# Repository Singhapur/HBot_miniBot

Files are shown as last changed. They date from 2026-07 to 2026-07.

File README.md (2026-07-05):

# 🤖 HBot_miniBot

Final Degree Project (Bachelor’s Thesis) repository to build a **miniBot** based on a distributed architecture using Arduino, Raspberry Pi, and ESP32.

This project documents the complete process, from physical construction (CAD design and 3D printing) to programming and integration of the different systems using ROS 2 and AI computer vision.

---

# 📌 Description

**HBot_miniBot** is an advanced educational and practical project that combines:

- **Low-Level Hardware Control:** Arduino for strict real-time motor PWM control and ESP32 for high-frequency (200Hz) telemetry (IMU & LiDAR).
- **High-Level Processing:** Raspberry Pi 5 acting as the brain, running ROS 2 (Ubuntu Server) for odometry, waypoint navigation, and Visual Servoing.
- **Artificial Intelligence:** Real-time human tracking using the YOLO11-pose model (Ultralytics) running directly on the edge.
- **Wireless Communication:** DDS network topology allowing seamless monitoring and teleoperation from a remote laptop via RViz2.

---

# 🏗 Construction

This section describes the complete miniBot building process. The chassis is 100% custom-designed focusing on modularity and maintenance.

- **Chassis design:** Modeled in CAD and optimized for FDM 3D printing.
- **Prototyping:** Dimensional validation performed using wood cardboard before final manufacturing.
- **Fabrication:** Final structural parts printed in PETG using an Original Prusa MK3S for superior thermal and mechanical resistance.
- **Hardware integration:** Tiered design (drive level, logic level, and sensor level). 

Images, schematics, and assembly recommendations will be included here.
imagen

---

# 📦 Bill of Materials (BOM)

## 🔩 Electronics

- Raspberry Pi 5 (Main brain)
- Arduino Uno / Nano (Motor & Actuator controller)
- ESP32 (Sensor bridge)
- Motor driver (L298N, L293D Shield, or similar)
- 1D LiDAR / Distance Sensor
- IMU (Inertial Measurement Unit)
- USB Camera
- 7.4V LiPo Battery (for motors)
- External power bank (5V 3A) for Raspberry Pi
- Breadboard and Dupont wires

## ⚙ Mechanics

- Custom 3D-Printed chassis (PETG)
- 4x TT DC motors with wheels and encoders
- 1x Servomotor (for camera/sensor panning)
- M3 Screws and nuts
- Brass standoffs / Spacers

---

# 💻 Software

The software architecture is divided into microcontroller firmware and a ROS 2 workspace. 

## 1. Microcontroller Firmware (C/C++)
Located in the `/arduino_esp_code` folder:
- **Arduino Code (arduino_code.ino):** Handles hardware interrupts for wheel encoders and translates binary serial commands into PWM signals for the DC motors. Includes an emergency stop trigger.
- **ESP32 Code (MPU_Luna.ino):** Samples the IMU and distance sensors at high speeds and streams the data to the Pi using a custom binary protocol with Checksum validation.

## 2. ROS 2 Workspace (Python)
Located in the `/robot_tfg_pkg/robot_tfg_pkg` folder. This is the core logic of the robot:

- `arduino_bridge.py` & `esp32_bridge.py`: Serial interfaces translating raw binary data to standard ROS 2 messages (`Twist`, `Imu`).
- `odometry_node.py`: Fuses encoder data with IMU gyroscope readings to estimate the robot's real-time position in the world.
- `camera_reader_yolo.py`: Captures video, runs YOLO11n-pose inference, and calculates visual servoing errors to center the target using the servo and chassis movement.
- `high_level_controller.py`: The main Finite State Machine (FSM). Handles pure alignment, waypoint navigation, deadband compensation, and emergency braking.
- `waypoint_sender.py`: A node that safely dispatches navigation coordinates once the DDS network is fully discovered.

---

# 🔧 Assembly

General assembly steps:

1. Validate dimensions with cardboard prototypes.
2. 3D Print the chassis layers in PETG.
3. Mount the TT motors and encoders onto the bottom chassis.
4. Attach the motor driver and power distribution system.
5. Install Arduino, Raspberry Pi, and ESP32 on their respective deck levels.
6. Mount the articulated neck for the camera and the top turret for the LiDAR.
7. Verify electrical connections (⚠ **Important:** Check polarities before powering the system).

## Testing Model

In this model we will see how the 3D model would actually look like, and also be able to start programming the functionalities.

- Base without ESP32 and Arduino case
  
  

- Completed base

  

- Testing model completed

  
  
## 3D Printed Model


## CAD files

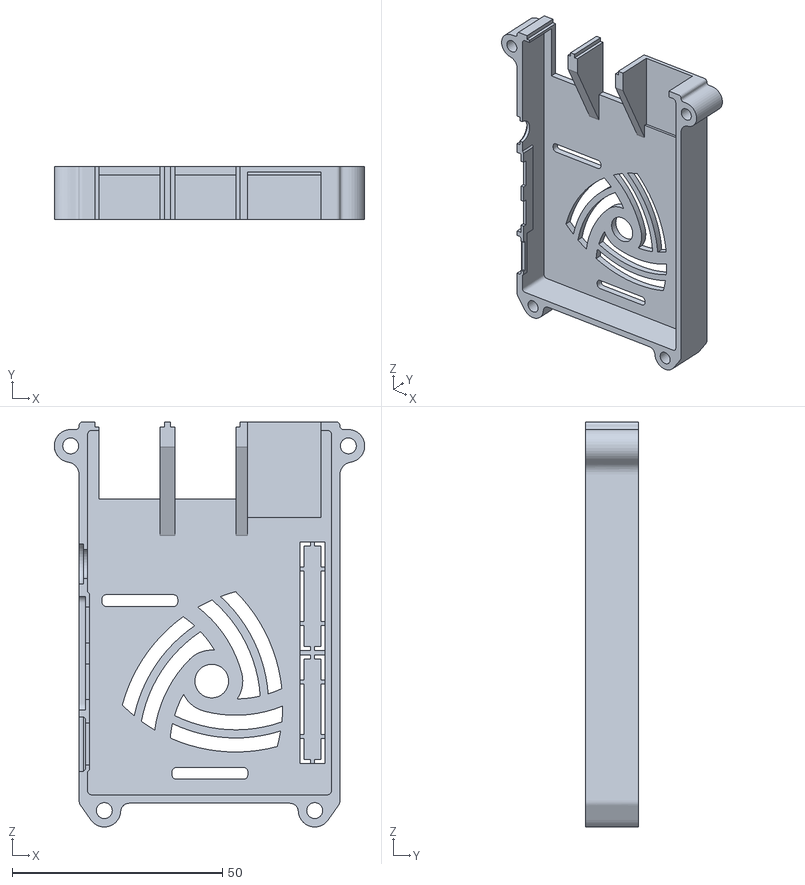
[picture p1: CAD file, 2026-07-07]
stl_models/Rpi_4_Case_Top_official_rPI_HDMI_cable.stl
73.8 x 12.5 x 96.2

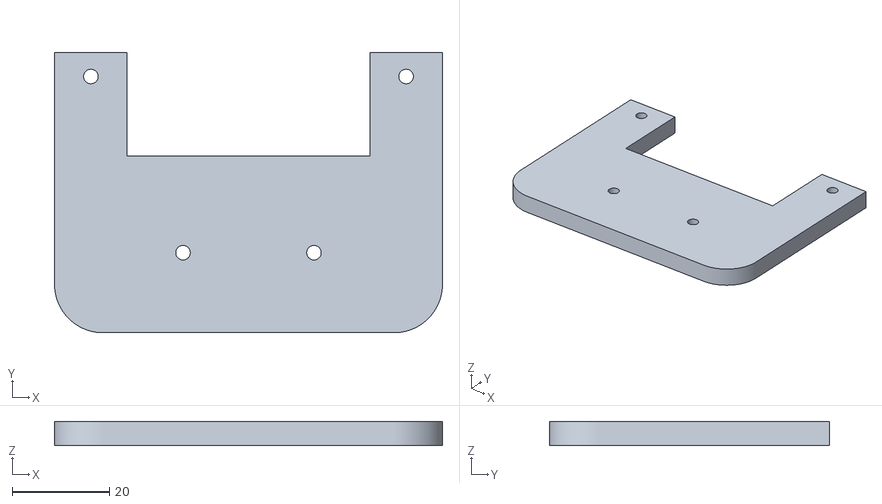
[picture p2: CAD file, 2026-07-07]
stl_models/PlataformaServo.stl
80.0 x 57.8 x 5.00

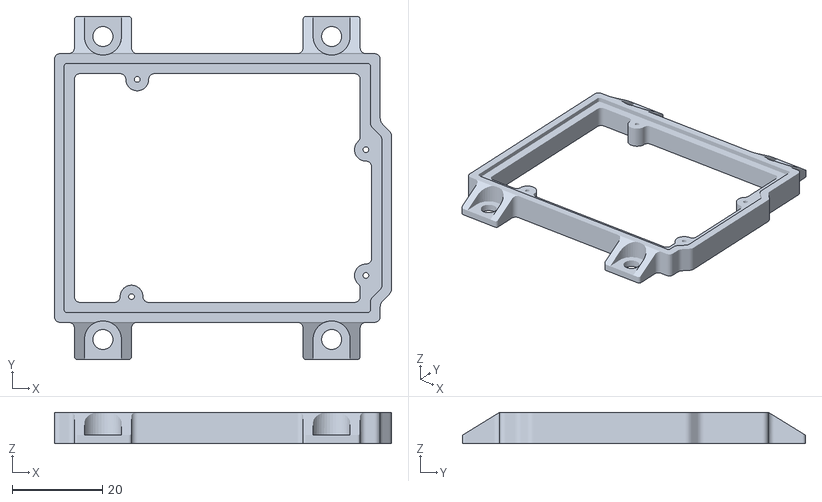
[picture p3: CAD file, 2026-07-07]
stl_models/UNO_R2_MOUNT.stl
74.9 x 76.2 x 6.99

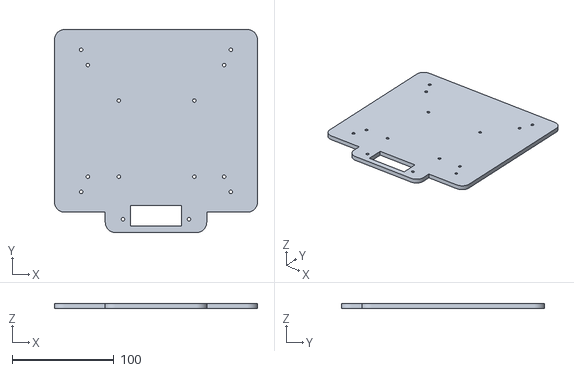
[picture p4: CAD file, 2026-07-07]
stl_models/Planta 2.stl
200.0 x 200.0 x 5.00

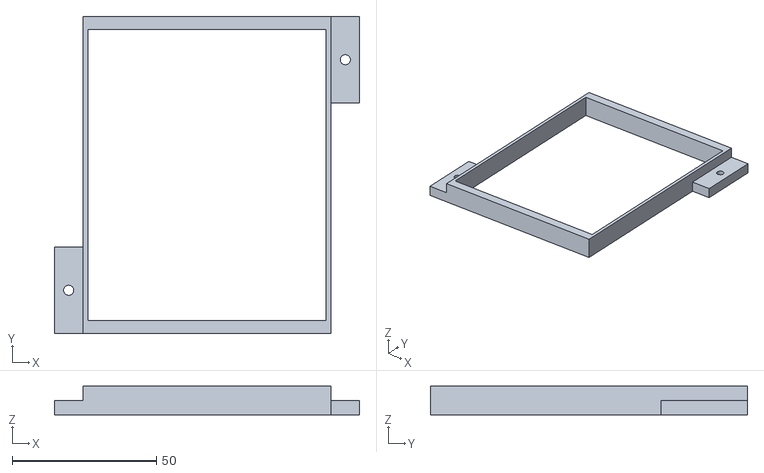
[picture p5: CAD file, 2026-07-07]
stl_models/protoboard case.stl
106.0 x 110.0 x 10.0

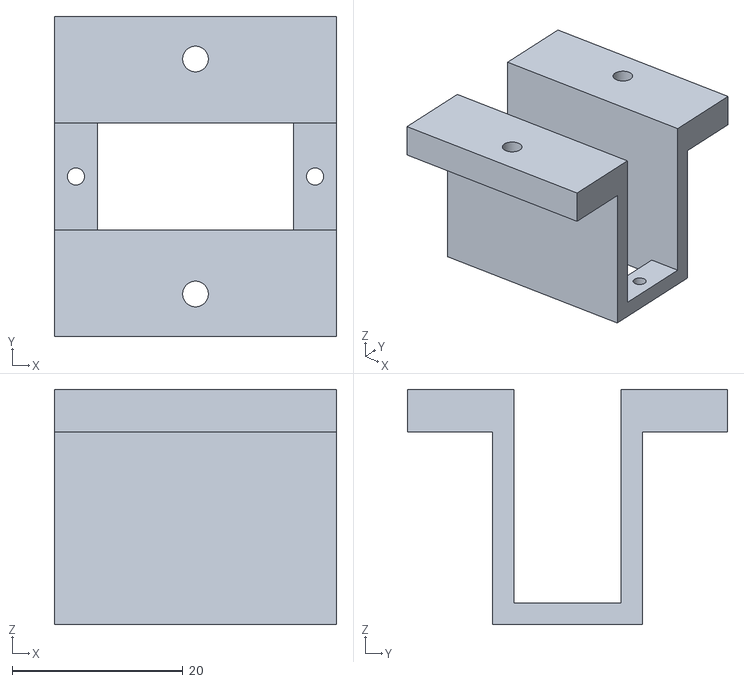
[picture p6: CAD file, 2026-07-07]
stl_models/soporte servo.stl
33.0 x 37.5 x 27.5

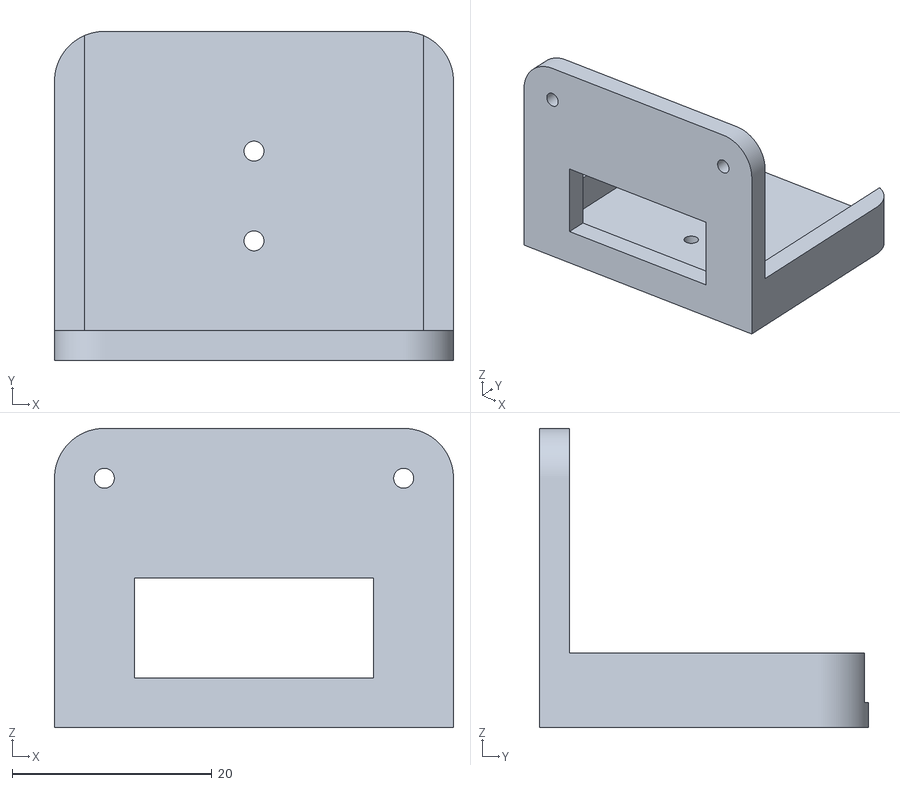
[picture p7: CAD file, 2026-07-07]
stl_models/Soporte Laser.stl
40.0 x 33.0 x 30.0

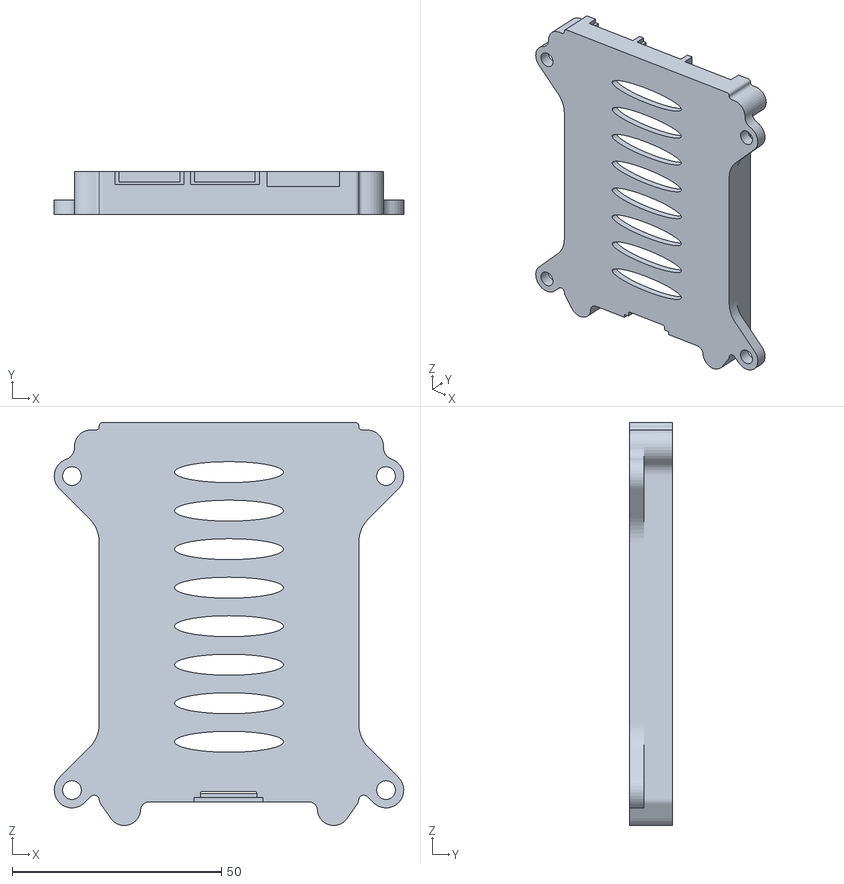
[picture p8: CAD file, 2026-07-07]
stl_models/Rpi_4_Case_Bottom_official_rPI_HDMI_cable.stl
83.5 x 10.3 x 96.2

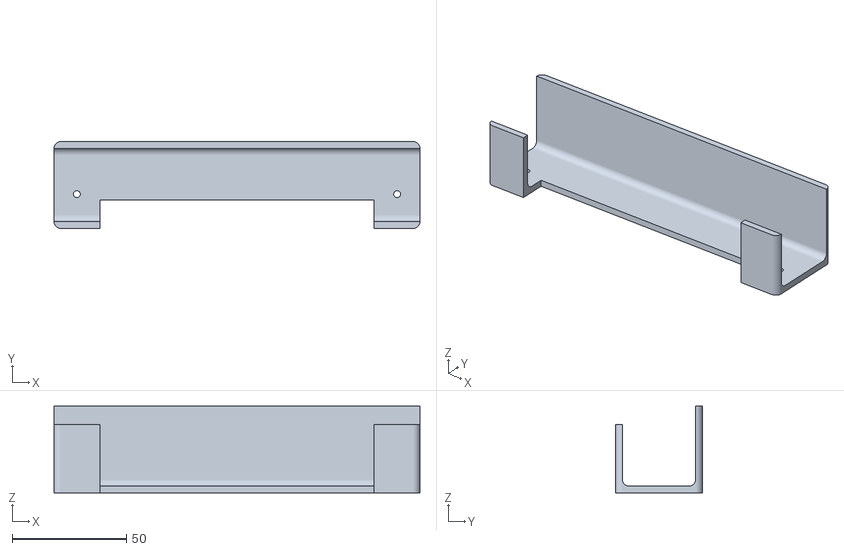
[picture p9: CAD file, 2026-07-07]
stl_models/Back Batery Suport.stl
160.0 x 38.0 x 38.0

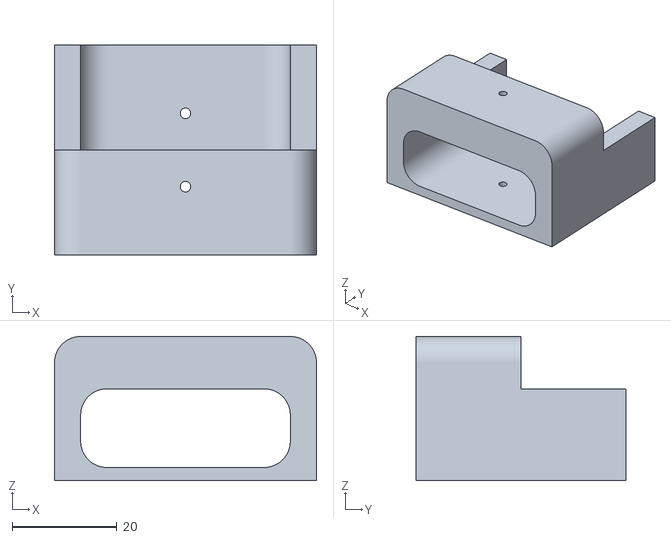
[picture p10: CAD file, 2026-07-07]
stl_models/Suport Camera.stl
50.0 x 40.0 x 27.5

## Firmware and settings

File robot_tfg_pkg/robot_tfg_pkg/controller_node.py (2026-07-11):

import rclpy
from rclpy.node import Node
from nav_msgs.msg import Odometry
from sensor_msgs.msg import Range
from geometry_msgs.msg import Twist
from std_msgs.msg import Int16MultiArray


class ControllerNode(Node):
    def __init__(self):
        super().__init__('controller_node')
        
        self.use_imu = True
        
        # Subscriptions
        self.sub_cmd_vel = self.create_subscription(Twist, '/cmd_vel', self.cmd_vel_callback, 10)
        self.sub_lidar = self.create_subscription(Range, '/sensor_distancia', self.distance_callback, 10)
        self.sub_odom = self.create_subscription(Odometry, '/odom', self.odom_callback, 10)
        
        # Publisher
        self.pub_pwm = self.create_publisher(Int16MultiArray, '/pwm_setpoints', 10)
        
        # Physical parameters
        self.wheelbase = 0.145
        self.max_speed_ms = 0.5

        # Smooth acceleration
        self.target_v = 0.0
        self.target_w = 0.0
        self.current_v = 0.0
        self.current_w = 0.0
        # Smooth acceleration variables 
        self.max_accel_v = 0.8 # m/s
        self.max_accel_w = 2.0 # rads/s

        self.max_decel_v = 5.0 # m/s 
        self.max_decel_w = 6.0 # rads/s
        self.dt = 0.1 # timer runs at 0.1 seconds
        
        # Sensor variables
        self.current_distance = 100.0 # meters
        self.min_distance = 0.20 # m  
        
        # State variables
        self.base_pwm_left = 0
        self.base_pwm_right = 0
        self.dir_left = 2 # 2=Release, 1=Forward, 0=Backward
        self.dir_right = 2
        self.straight_line_mode = False
        self.last_cmd_time = self.get_clock().now()
        self.last_pwm_left = 0
        self.last_pwm_right = 0
        
        
        # Memory for the Integral term
        self.error_fwd = 0.0
        self.error_bwd = 0.0
        
        # Timer to send PWM commands constantly
        self.timer = self.create_timer(0.1, self.publish_pwm)
        
        # PI Controller parameters
        self.kp = 4.5
        self.ki = 1.0

        # Deadband compensation
        self.MIN_PWM_STRAIGHT = 110
        self.MIN_PWM_TURN = 140
        
        self.get_logger().info('Trajectory PI Controller Started')
        
    def distance_callback(self, msg):
        self.current_distance = msg.range

    def cmd_vel_callback(self, msg):
        self.last_cmd_time = self.get_clock().now()
        v = msg.linear.x
        w = msg.angular.z
        self.target_v = msg.linear.x
        self.target_w = msg.angular.z

        if self.current_distance <= self.min_distance and self.target_v > 0:
            self.target_v = 0.0
            self.target_w = 0.0
            self.current_v = 0.0
            self.current_w = 0.0

    def odom_callback(self, msg):
        # We could use odometry data for additional control or state estimation if needed
        real_w = msg.twist.twist.angular.z

        # Apply PI if going in a straight line
        if self.straight_line_mode:
            
            error = -real_w * 10.0 
            
            integral_term = 0.0
            
            # Save error for Anti-Windup
            if self.dir_left == 1 and self.dir_right == 1:
                self.error_fwd += error
                self.error_fwd = max(-50.0, min(50.0, self.error_fwd))
                integral_term = self.error_fwd
                
            elif self.dir_left == 0 and self.dir_right == 0:
                self.error_bwd += error
                self.error_bwd = max(-50.0, min(50.0, self.error_bwd))
                integral_term = self.error_bwd

            # Correction Calculation: Proportional + Integral
            correction = int((error * self.kp) + (integral_term * self.ki))
            
            # Apply correction to the base PWM
            if self.last_pwm_left != 0 and self.last_pwm_right != 0:
                self.base_pwm_left = self.last_pwm_left - correction
                self.base_pwm_right = self.last_pwm_right + correction
            else:
                self.base_pwm_left -= correction
                self.base_pwm_right += correction
            
            self.base_pwm_left = max(95, min(255, self.base_pwm_left))
            self.last_pwm_left = self.base_pwm_left       
            self.base_pwm_right = max(95, min(255, self.base_pwm_right))
            self.last_pwm_right = self.base_pwm_right


    def assign_vel(self):
        # Smooth acceleration logic
        # Calculate the difference between what we want and what we have
        dv = self.target_v - self.current_v
        dw = self.target_w - self.current_w
        
        # We brake if the absolute target is smaller than the current one, or if we suddenly change direction
        is_braking_v = abs(self.target_v) < abs(self.current_v) or (self.target_v * self.current_v < 0)
        is_braking_w = abs(self.target_w) < abs(self.current_w) or (self.target_w * self.current_w < 0)
        
        # Assign the corresponding step limit
        step_limit_v = (self.max_decel_v if is_braking_v else self.max_accel_v) * self.dt
        step_limit_w = (self.max_decel_w if is_braking_w else self.max_accel_w) * self.dt
        
        # Apply linear ramp
        if abs(dv) > step_limit_v:
            self.current_v += step_limit_v if dv > 0 else -step_limit_v
        else:
            self.current_v = self.target_v
            
        # Apply angular ramp
        if abs(dw) > step_limit_w:
            self.current_w += step_limit_w if dw > 0 else -step_limit_w
        else:
            self.current_w = self.target_w

        # 3. Set speed
        v = self.current_v
        w = self.current_w

        # Straight line
        if abs(v) > 0.01 and abs(w) < 0.01:
            self.straight_line_mode = True
        else:
            self.straight_line_mode = False

        turn_factor = 1.0

        v_left = v - (w * turn_factor * self.wheelbase / 2.0)
        v_right = v + (w * turn_factor * self.wheelbase / 2.0)

        pwm_l = int(abs(v_left) * (255.0 / self.max_speed_ms))
        pwm_r = int(abs(v_right) * (255.0 / self.max_speed_ms))

        # Deadband compensation
        
        if self.straight_line_mode:      
            if 0 < pwm_l < self.MIN_PWM_STRAIGHT: pwm_l = self.MIN_PWM_STRAIGHT
            if 0 < pwm_r < self.MIN_PWM_STRAIGHT: pwm_r = self.MIN_PWM_STRAIGHT
        else:
            if 0 < pwm_l < self.MIN_PWM_TURN: pwm_l = self.MIN_PWM_TURN
            if 0 < pwm_r < self.MIN_PWM_TURN: pwm_r = self.MIN_PWM_TURN

        # Save the BASE from the kinematic calculation
        self.base_pwm_left = min(255, pwm_l)
        self.base_pwm_right = min(255, pwm_r)

        # Directions
        if v_left > 0.01: self.dir_left = 1
        elif v_left < -0.01: self.dir_left = 0
        else: self.dir_left = 2

        if v_right > 0.01: self.dir_right = 1
        elif v_right < -0.01: self.dir_right = 0
        else: self.dir_right = 2

    def publish_pwm(self):
        time_since_last_cmd = (self.get_clock().now() - self.last_cmd_time).nanoseconds / 1e9       
        # Watchdog: Stop robot if no command received in 0.2s
        if time_since_last_cmd > 0.2:
            self.base_pwm_left = 0
            self.base_pwm_right = 0
            self.dir_left = 2  # Release
            self.dir_right = 2 # Release
            self.straight_line_mode = False
            self.error_fwd = 0.0
            self.error_bwd = 0.0
            # New target for smooth stop
            self.target_v = 0.0
            self.target_w = 0.0
        
        self.assign_vel() 
            
        # Convert absolute values to signed values (positive/negative)
        val_left = self.base_pwm_left if self.dir_left == 1 else -self.base_pwm_left
        if self.dir_left == 2: val_left = 0
        
        val_right = self.base_pwm_right if self.dir_right == 1 else -self.base_pwm_right
        if self.dir_right == 2: val_right = 0
        
        msg_pwm = Int16MultiArray()
        msg_pwm.data = [val_left, val_right]
        self.pub_pwm.publish(msg_pwm)

def main(args=None):
    rclpy.init(args=args)
    node = ControllerNode()
    rclpy.spin(node)
    node.destroy_node()
    rclpy.shutdown()

if __name__ == '__main__':
    main()

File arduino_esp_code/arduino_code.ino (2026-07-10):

#include "AFMotor_R4.h"
#include <Servo.h>
#include <EnableInterrupt.h>

// --- BINARY COMMUNICATION PROTOCOL ---
#define START_BYTE 0xAA
#define END_BYTE   0x55
#define ID_ENCODERS 0x02
#define ID_CMD_MOTOR_SERVO 0x10

// --- DC MOTOR CONFIGURATION ---
AF_DCMotor M1(1); // Front left
AF_DCMotor M2(2); // Front right
AF_DCMotor M3(3); // Rear right
AF_DCMotor M4(4); // Rear left

// --- TWO SERVO CONFIGURATION ---
Servo cameraServo;
Servo lidarServo;

// --- ROBOT STATES ---
int left_pwm = 0;
int left_dir = RELEASE;
int right_pwm = 0;
int right_dir = RELEASE;
int camera_angle = 90;
int lidar_angle = 90;
int motor_watchdog = 0; // Watchdog timer

// --- ENCODERS ---
const byte pinEncFL = A0;
const byte pinEncFR = A1;
const byte pinEncRL = A2;
const byte pinEncRR = A3;

// We use uint8_t because we send the encoder delta every 50 ms
volatile uint8_t ticks_FL = 0;
volatile uint8_t ticks_FR = 0;
volatile uint8_t ticks_RL = 0;
volatile uint8_t ticks_RR = 0;

uint8_t encoder_buffer[4];
unsigned long last_loop_time = 0;

// --- INTERRUPT ROUTINES (PCINT) ---
void countFL() { ticks_FL++; }
void countFR() { ticks_FR++; }
void countRL() { ticks_RL++; }
void countRR() { ticks_RR++; }

// ==========================================
// FUNCTION TO SEND BINARY DATA
// ==========================================
void sendMessage(uint8_t id, uint8_t* data, uint8_t len) {
  Serial.write(START_BYTE);
  Serial.write(id);
  Serial.write(len);

  uint8_t checksum = id ^ len;
  for (uint8_t i = 0; i < len; i++) {
    Serial.write(data[i]);
    checksum ^= data[i];
  }

  Serial.write(checksum);
  Serial.write(END_BYTE);
}

// ==========================================
// STATE MACHINE TO RECEIVE BINARY DATA
// ==========================================
void receiveMessage() {
  static enum { WAIT_START, READ_ID, READ_LEN, READ_DATA, READ_CHK, WAIT_END } state = WAIT_START;
  static uint8_t buffer[10];
  static uint8_t idx = 0;
  static uint8_t id, len, checksum;

  while (Serial.available()) {
    uint8_t byte_in = Serial.read();

    switch (state) {
      case WAIT_START:
        if (byte_in == START_BYTE) state = READ_ID;
        break;

      case READ_ID:
        id = byte_in;
        checksum = id;
        state = READ_LEN;
        break;

      case READ_LEN:
        len = byte_in;
        checksum ^= len;
        idx = 0;

        if (len > 10)
          state = WAIT_START;
        else
          state = READ_DATA;
        break;

      case READ_DATA:
        buffer[idx++] = byte_in;
        checksum ^= byte_in;

        if (idx >= len)
          state = READ_CHK;
        break;

      case READ_CHK:
        if (byte_in == checksum)
          state = WAIT_END;
        else
          state = WAIT_START;
        break;

      case WAIT_END:
        if (byte_in == END_BYTE) {
          // If this is a motion command containing 6 data bytes
          // (LeftDir, LeftPWM, RightDir, RightPWM, Camera, LiDAR)
          if (id == ID_CMD_MOTOR_SERVO && len == 6) {

            left_dir = (buffer[0] == 0) ? BACKWARD :
                       (buffer[0] == 1) ? FORWARD : RELEASE;
            left_pwm = buffer[1];

            right_dir = (buffer[2] == 0) ? BACKWARD :
                        (buffer[2] == 1) ? FORWARD : RELEASE;
            right_pwm = buffer[3];

            camera_angle = buffer[4];
            lidar_angle = buffer[5];

            // Reset the watchdog timer (500 ms)
            motor_watchdog = 10;
          }
        }

        state = WAIT_START;
        break;
    }
  }
}

// ==========================================
// APPLY VALUES TO THE HARDWARE
// ==========================================
void applyHardware() {
  M1.run(left_dir);
  M1.setSpeed(left_pwm);

  M4.run(left_dir);
  M4.setSpeed(left_pwm);

  M2.run(right_dir);
  M2.setSpeed(right_pwm);

  M3.run(right_dir);
  M3.setSpeed(right_pwm);

  cameraServo.write(camera_angle);
  lidarServo.write(lidar_angle);
}

// Arduino setup
void setup() {
  Serial.begin(115200);

  cameraServo.attach(10);
  cameraServo.write(camera_angle);

  lidarServo.attach(9);
  lidarServo.write(lidar_angle);

  pinMode(pinEncFL, INPUT_PULLUP);
  pinMode(pinEncFR, INPUT_PULLUP);
  pinMode(pinEncRL, INPUT_PULLUP);
  pinMode(pinEncRR, INPUT_PULLUP);

  enableInterrupt(pinEncFL, countFL, RISING);
  enableInterrupt(pinEncFR, countFR, RISING);
  enableInterrupt(pinEncRL, countRL, RISING);
  enableInterrupt(pinEncRR, countRR, RISING);
}

void loop() {
  unsigned long now = millis();

  // LISTEN TO THE RASPBERRY PI WITHOUT BLOCKING
  receiveMessage();

  // EXECUTE TASKS EVERY 50 ms
  if (now - last_loop_time >= 50) {
    last_loop_time = now;

    // Read encoder values while briefly disabling interrupts
    noInterrupts();
    encoder_buffer[0] = ticks_FL; ticks_FL = 0;
    encoder_buffer[1] = ticks_FR; ticks_FR = 0;
    encoder_buffer[2] = ticks_RL; ticks_RL = 0;
    encoder_buffer[3] = ticks_RR; ticks_RR = 0;
    interrupts();

    // Send odometry data
    sendMessage(ID_ENCODERS, encoder_buffer, 4);

    // Watchdog
    if (motor_watchdog > 0) {
      motor_watchdog--;
    } else {
      left_dir = RELEASE;
      left_pwm = 0;
      right_dir = RELEASE;
      right_pwm = 0;
    }

    // Update motors and servos
    applyHardware();
  }
}

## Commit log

2026-02-26 Revise README.md with project details and structure
    Updated README.md to provide detailed project documentation for HBot_miniBot, including construction, assembly, software requirements, and future improvements.
2026-04-26 Add boot code
    [robot.urdf]
2026-04-26 Add Arduino and ESP code
2026-04-26 modify radar code and esp bridge code for solve lost package problems
    [arduino_bridge.py, controller_node.py, esp32_bridge.py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]
2026-04-27 Modify for solve radar laser issues and change rader range to 4m
    [robot.urdf]
2026-05-04 Add camera package
2026-05-05 Add camera publisher and camera subscriber
2026-05-06 Add image compress for ros2 and camera
2026-05-07 Add image compress to publisher and camera_reader
2026-05-07 Add safety stop and correct fome import format
    [arduino_bridge.py, camera_publish.py, controller_node.py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]
2026-05-09 correct error for emergency stop from distance
    [controller_node.py]
2026-05-14 Add logic for folow an person with the camera
2026-05-15 Increment error for send servo angle
2026-05-18 Add home pose to camera reader
2026-06-01 Modify controler to work only with odom and correct instruction issues
    [controller_node.py]
2026-06-07 Add auto calibration for giroscop
2026-06-09 modify high and normal controller for more smooth control and increase ledar stop distance
2026-06-15 Add new camera model and modify some high level controler code
2026-06-16 Correct fom issues of movment
    [camera_reader_yolo.py, high_level_controller.py]
2026-06-18 change logic of camare folow yolo and incease calibration value of odometry
2026-06-18 Add new logig in high level controller and change calibration in odometry
2026-06-20 Change yolo folow code and add some timers
2026-07-07 Change camera reader script to camera_reader_yolo.py
    Updated the script to launch the YOLO camera reader instead of the previous camera reader.
2026-07-07 upload stl models
    [Back Batery Suport.stl, Planta 2.stl, PlataformaServo.stl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]
